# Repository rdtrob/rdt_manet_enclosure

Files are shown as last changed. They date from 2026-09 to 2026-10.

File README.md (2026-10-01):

# RDT MANET Radio Enclosure

A 3D-printable, weather-resistant and waterproof enclosure for a portable mesh radio node built around the Raspberry Pi Compute Module 4, Waveshare Mini Base Board (A), MediaTek MT7916 Wi-Fi 6E card and a Morse Micro MM8108 Wi-Fi HaLow board.

The enclosure was designed for the [very-srs/MANET](https://github.com/very-srs/MANET) project (on the Waveshare CM4 carrier board), but it should also fit hardware deployments of [OpenMANET](https://github.com/openmanet) (Raspberry Pi 4/5) with minimal to no required modifications.

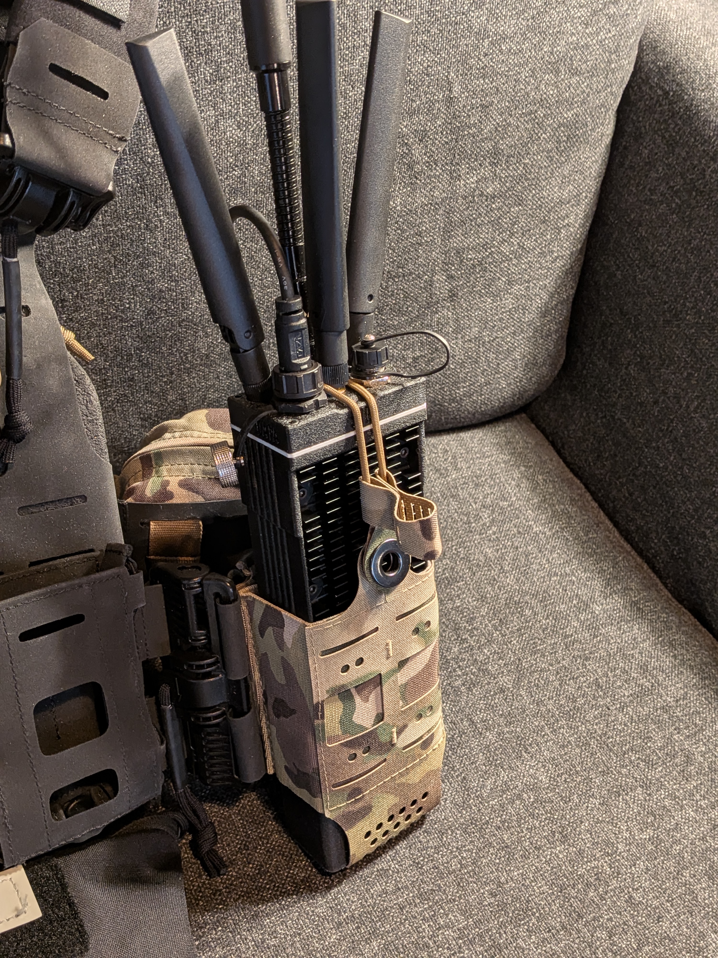
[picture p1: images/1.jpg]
Plate carrier presentation

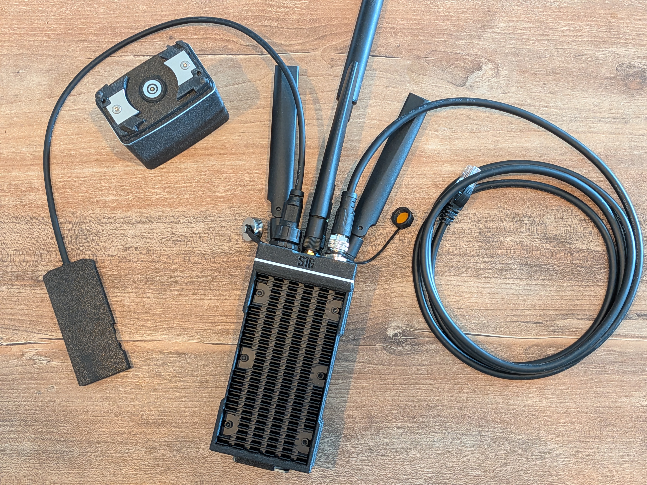
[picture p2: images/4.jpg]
Assembled enclosure with accessories, next to battery.


More pictures can be found in [images/](images/)

---

## Table of Contents

- [Overview](#overview)
- [Features](#features)
- [Compatible Hardware](#compatible-hardware)
- [Bill of Materials](#bill-of-materials)
- [Repository Structure](#repository-structure)
- [Printing](#printing)
- [Assembly](#assembly)
- [Power](#power)
- [Thermal Notes](#thermal-notes)
- [RF Notes](#rf-notes)
- [Software](#software)
- [Contributing](#contributing)
- [License](#license)
- [Disclaimer](#disclaimer)
- [Acknowledgements](#acknowledgements)

---

## Overview

This repository contains the printable parts (STL) for a self-contained MANET radio node. The enclosure houses:

- **Raspberry Pi CM4** on a **Waveshare Mini Base Board (A)** carrier,
- **MT7916 Wi-Fi 6E M.2 A/E-key card**, mounted in the carrier's M.2 M-key slot through an **M.2 M-key → A/E-key adapter (Note: Only two of the three antennas send, specifically 1 and 2, the ones on the short end of the MT7916 board. The 3rd is only receiving on 5GHz in 2T3R mode.)**,
- **Lunpid Morse Micro MM8108 Wi-Fi HaLow** board connected over USB-C,
- **Pololu D36V28F5** 5 V step-down regulator,

and exposes three SMA antenna ports for the MT7916, one SMA port for the HaLow radio, a waterproof USB-C port, an M12 connector to internal Ethernet port and a magnetic pogo-pin power input.

## Features

- Fully 3D-printable body, no custom PCBs required
- 3× SMA bulkhead mounts for 2.4 / 5 / 6 GHz MIMO antennas (Note: see reference to antenna positioning in the [Overview](#overview) section above, subsection MT7916)
- 1× SMA bulkhead mount for the sub-GHz HaLow antenna
- Waterproof panel-mount USB-C for access to the carrier board
- M12 connector for ruggedized wired Ethernet
- 3-pin magnetic pogo-pin power input, regulated on board to 5 V
- Heat-set-insert design using M2.5 and M3 hardware
- Cables

## Compatible Hardware

| Component | Model | Notes |
|---|---|---|
| Compute | Raspberry Pi Compute Module 4 — CM4004032 | 4 GB RAM, 32 GB eMMC, **no** onboard Wi-Fi/BT requried |
| Carrier | Waveshare Mini Base Board (A) (CM4-IO-BASE-A) | Gigabit Ethernet, 2× USB 2.0, M.2 M-key (PCIe), 5 V USB-C input |
| Wi-Fi 6E | AsiaRF AW7916-AED (MediaTek MT7916AN) | M.2 A/E-key, 2.4 GHz 2T2R + 5/6 GHz, 3× IPEX antenna connectors |
| M.2 adapter | M.2 M-key → M.2 A/E-key adapter | Lets the A/E-key Wi-Fi card sit in the carrier's M-key slot |
| HaLow | Morse Micro MM8108 board | 802.11ah, connected to the carrier via USB-C |
| Regulator | Pololu D36V28F5 | 5 V, 3.2 A step-down; wide input range |
| Heatsink - MT7916 | Wakefield 559-50AB-ND | Heatsink for MT7916 card

Other CM4 variants (different RAM/eMMC sizes) fit the same carrier. Variants **with** onboard wireless also fit, but their onboard antenna will be shielded by the enclosure and are also not used.

## Bill of Materials

The full parts list, with quantities and supplier links, is in **[BOM.md](BOM.md)**.

Summary of what you'll need beyond the printed parts:

- Core electronics: CM4, carrier board, MT7916 card, M.2 adapter, MM8108 HaLow board, Pololu regulator
- Antennas: 3× SMA (2.4/5/6 GHz) + 1× SMA adapter for HaLow board
- Connectors and cables: waterproof USB-C, M12 Ethernet, magnetic pogo-pin power, USB-A to USB-C adapter, internal USB-C cables
- Hardware: Heatsink, M2.5 and M3 screws, M3 nuts

## Repository Structure

```
.
├── stl/              # Printable parts
├── source/           # Editable CAD source files (STEP / native format) #To be potentially added in the future
├── images/           # Photos and renders
├── docs/             # Additional assembly or wiring notes
├── BOM.md            # Bill of materials
├── LICENSE           # GNU GPL v3.0
└── README.md
```

| File | Part | Qty |
|---|---|---|
| `stl/Unibody.stl` | Main body  to be printed in PA6-GF | 1 |
| `stl/TopConnectorPlate.stl` | Top I/O plate - PA6-GF | 1 |
| `stl/BackPanel.stl` | Back panel - PA6-GF | 1 |
| `stl/TPU_gasket_back.stl` | Back gasket to be printed in TPU | 1 |
| `stl/TPU_gasket_top` | Top gasket - TPU | 1 |
| `stl/Connector_MagneticPogoPIN_mount` | Pogo-pin connector mounting bracket - PA6-GF | 1 |
| `stl/Connector_MagneticPogoPIN_TPU_gasket` | Pogo-pin connector gasket - TPU | 1 |

## Printing

Recommended settings (adjust for your printer):

| Setting | Value |
|---|---|
| Material | PA6-GF or PETG-CF for enclosure and TPU for gaskets|
| Layer height | 0.08 mm |
| Walls / perimeters | 2 - 4 |
| Infill | 35 %  to 45 % |
| Supports | Default, tree |
| Nozzle | 0.4 mm |

Notes:
- Avoid PLA for field units: it softens in direct sunlight and in a warm vehicle.
- Print the body with the bottom side up ( battery connector facing upwards ) or front-facing open side up for the cleanest sealing surface.
- Print with supports. Yes, there's some filament loss in support material on the BackPanel and TopConnectorPlate designs but the prints come out clean, with minimal to no retouching required.
- Test-fit the SMA bulkheads and M12 connector before final assembly; hole tolerances vary between printers.
- For waterproof-sealing, treat all printed components with a polimer sealant like Diamant's Dichtol AM Hydro (Note: link provided in **[BOM.md](BOM.md)**)

## Assembly

<!-- TODO: expand with photos per step -->

1. **Prepare the compute stack.** Seat the CM4 on the Waveshare carrier. Install the M.2 M→A/E adapter in the carrier's M.2 slot and fit the MT7916 card to the adapter.
2. **Attach antenna pigtails.** Connect the three IPEX leads to the MT7916 card before mounting it; access is limited once installed.
3. **Mount bulkhead connectors.** Install the 3× SMA bulkheads, the HaLow SMA, the waterproof USB-C, the M12 connector and the magnetic pogo-pin connector in the enclosure walls.
4. **Mount the carrier.** Fix the carrier into the body with M2.5 screws.
5. **Mount the Pololu regulator** with M3 hardware and wire it: pogo-pin input → Pololu VIN/GND, Pololu 5 V output → USB-C cable → carrier board power input.
6. **Mount the HaLow board** and connect it to the carrier with the short USB-C to USB-C cable. Connect its antenna lead to the HaLow SMA bulkhead.
7. **Connect Ethernet:** carrier RJ45 → M12 internal cable.
8. **Close the enclosure** with M3 screws and nuts. Check that no cable is pinched at the lid seam.

## Power

```
[External source] ──► 3-pin magnetic pogo connector ──► Pololu D36V28F5 (5 V) ──► USB-C ──► Waveshare carrier
                                                                                              ├── CM4
                                                                                              ├── M.2 → MT7916 (3.3 V rail)
                                                                                              └── USB-C → MM8108 HaLow
```

- The D36V28F5 accepts a wide input range and outputs a regulated 5 V. **Check the input limits on the Pololu product page before connecting any source.**
- Double-check pogo-pin polarity before first power-up. There is no reverse-polarity protection in this design unless you add it. <!-- TODO: confirm -->
- The Waveshare carrier's 5 V input is specified for about 2.5 A. The MT7916 card is the biggest single load; see below.

## Thermal Notes

- The MT7916 card can draw several watts under load and needs its heatsink fitted.
- The CM4 benefits from a heatsink, especially in a sealed enclosure. 
- A sealed printed enclosure has limited heat dissipation. For sustained high-throughput use or hot climates, consider reducing Wi-Fi TX power or adding ventilation.

## RF Notes

- Use antennas rated for the bands you operate on (2.4 / 5 / 6 GHz for the MT7916; your regional sub-GHz band for HaLow).
- Never transmit without antennas connected, can damage components.
- Keep IPEX-to-SMA pigtails short and avoid sharp bends.
- **You are responsible for operating within your local regulatory limits** (channels, transmit power, EIRP, 6 GHz availability).

## Software

This repository contains **hardware only**. For firmware and mesh configuration see:

- [very-srs/MANET](https://github.com/very-srs/MANET). This enclosure is primarily designed for use with the very-srs project but can fit OpenMANET as well.
- [OpenMANET](https://github.com/openmanet)

## Contributing

Issues and pull requests are welcome.

- Describe what you changed and why (fit issue, new variant, print improvement).
- Include the **editable source file** along with any updated STL.
- Note the printer, material and settings you tested with.
- Photos of printed or assembled parts are very helpful.

## License

This project is licensed under the **GNU General Public License v3.0**. See [LICENSE](LICENSE).

You may use, modify and redistribute these files, including commercially, provided that any distributed derivative is released under the same license and includes its corresponding source files.

Third-party components listed in the BOM are the property of their respective manufacturers and are not covered by this license.

## Disclaimer

This design is provided **as is, without warranty of any kind**. You assume all risk associated with building, powering and operating this device, including electrical safety, battery handling, weatherproofing and radio-regulatory compliance.

## Acknowledgements

- [very-srs/MANET](https://github.com/very-srs/MANET) and [OpenMANET](https://github.com/openmanet) projects.
- Raspberry Pi, Waveshare, AsiaRF, Morse Micro and Pololu for the hardware.

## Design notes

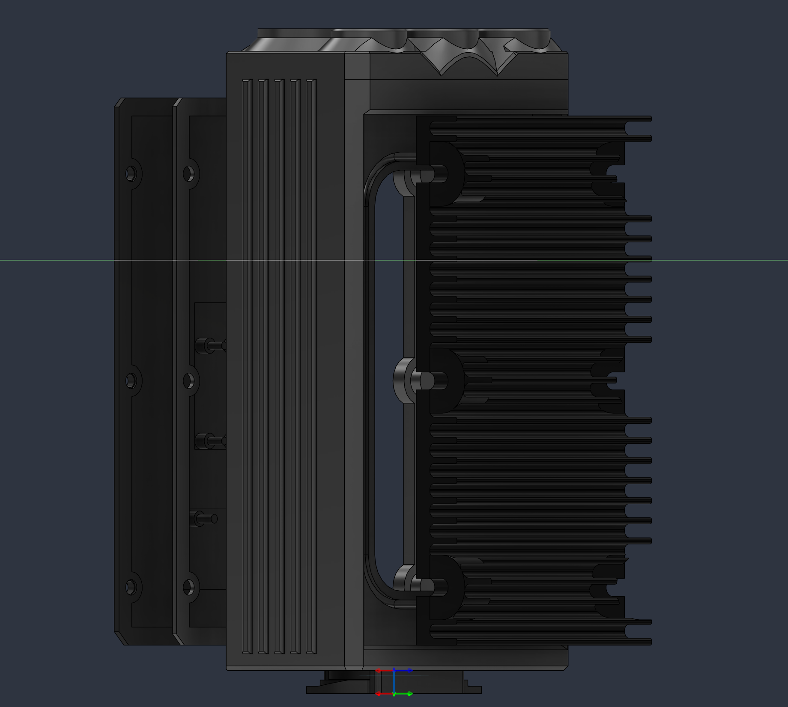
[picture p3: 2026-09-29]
images/render/render_4.png

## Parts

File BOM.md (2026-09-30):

# Bill of Materials

Parts required to build one radio node. Printed parts are listed in the [README](README.md#repository-structure).

Links are provided for reference only; equivalent parts from other suppliers should work unless noted.

## Electronics

| # | Name | Description | Amount | Link |
|---|---|---|---|---|
| 1 | Raspberry Pi Compute Module 4 | CM4004032: 4 GB RAM, 32 GB eMMC, no onboard Wi-Fi/BT | 1 | [PiShop](https://www.pishop.us/product/raspberry-pi-compute-module-4-4gb-32gb-cm4004032/) |
| 2 | CM4 carrier board | Waveshare Mini Base Board (A) (CM4-IO-BASE-A) | 1 | [Eckstein](https://eckstein-shop.de/WaveShareMiniBaseBoardADesignedforRaspberryPiComputeModule4) |
| 3 | MT7916 Wi-Fi 6E board | AsiaRF AW7916-AED, M.2 A/E-key, MediaTek MT7916AN | 1 | [AsiaRF](https://asiarf.com/product/wi-fi-6e-m-2-ae-key-module-mt7916-aw7916-aed/) |
| 4 | M.2 A/E-key adapter | M.2 M-key to M.2 A/E-key adapter for the Wi-Fi board | 1 | [AliExpress](https://www.aliexpress.com/item/4000175123887.html) |
| 5 | MM8108 HaLow board | Morse Micro MM8108 Wi-Fi HaLow (802.11ah) board | 1 | [Shopify Lunpid](https://lunpid.com/products/usb-mm8108-halow) |
| 6 | Pololu buck converter | Pololu D36V28F5, 5 V 3.2 A step-down regulator | 1 | [Pololu](https://www.pololu.com/product/3782) |

## Antennas and RF

| # | Name | Description | Amount | Link |
|---|---|---|---|---|
| 7 | SMA antenna | 2.4 / 5 / 6 GHz antenna for the MT7916 board | 3 | [Farnell](https://www.newark.com/siretta/delta47-smam-36/rf-antenna-600mhz-5-6ghz/dp/97AK2184) |
| 8 | SMA antenna (HaLow) | 868 MHz SMA antenna for the Lunpid MM8108 HaLow board | 1 | [Hexaspot 868MHz gooseneck antenna](https://hexaspot.com/products/hexaspot-tactical-gooseneck-antenna-868mhz?variant=57776200810827) |
| 9 | SMA cable, 2.4/5GHz | IPEX MHF 1 - SMA female cable assembly for MT7916 board | 3 | [TME](https://www.tme.eu/en/details/ipex-sma-150/coaxial-assemblies/onteck)
| 10 | SMA cable, sub 1GHz | Ccable for SMA male to SMA female adapter for the MM8108 HaLow board antenna | 1 | [AliExpress](https://www.aliexpress.com/item/1005003433705318.html) |

## Connectors and Cables

| # | Name | Description | Amount | Link |
|---|---|---|---|---|
| 11 | Waterproof USB-C connector | Panel-mount waterproof USB-C, wired to the carrier board | 1 | [AliExpress](https://www.aliexpress.com/item/1005006218980573.html) |
| 12 | USB-C cable & connector (Pololu → carrier) | Cable with USB-C plug carrying 5 V from the Pololu board to the carrier board | 1 | [AliExpress](https://www.aliexpress.com/item/1005011867528852.html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) |
| 13 | Pololu → pogo-pin cable | Cable from the Pololu input to a 3-pin magnetic pogo-pin connector | 1 | [AliExpress](N/A) |
| 14 | Magnetic Pogo 3 Pin connector | Panel-mount circular 12mm connector, wired to the #11 cable. Connects to the off-set connector on the battery enclosure. | 1 | [AliExpress](https://www.aliexpress.com/item/1005008792560196.html#nav-specification)
| 15 | USB-C snap connector UC1 | Snap USB-C connector, Lunpid MM8108 HaLow board | 1 | [AliExpress](https://www.aliexpress.com/item/1005008383845058.html) |
| 15 | Ribbon cable for USB-C snap connector | Short cable, carrier board to Lunpid MM8108 HaLow USB-C snap connector | 1 | [AliExpress](https://www.aliexpress.com/item/1005008383845058.html) |
| 16 | M12 connector | Panel-mount M12 connector for Ethernet. Pick Male Back M12-P-GCFM-16-NZG 8Pin variant. | 1 | [AliExpress](https://www.aliexpress.com/item/1005012293627764.html) |
| 17 | Flat Ethernet connector | Internal connector, M12 connector to carrier RJ45 port | 1 | [AliExpress](https://www.aliexpress.com/item/1005005257546532.html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) |
| 18 | USB adapter | USB-A to USB-C(female) adapter for external USB-C connector to be plugged into the carrier board | 1 | [AliExpress](https://www.aliexpress.com/item/1005009180629876.html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) |

## Hardware

| # | Name | Description | Amount | Link |
|---|---|---|---|---|
| 19 | Heatsink for MT7916 | Wakefield 559-50AB-ND heatsink | 1 | [Wakefield 559-50AB](https://www.digikey.com/en/products/detail/wakefield-thermal-solutions/559-50ab/5068188)* |
| 20 | M2.5 screws | Hex M2.5x7mm | 4 | N/A |
| 21 | M3 screws, back plate | Hex M3x6mm, mounting the back plate | 6 | N/A |
| 22 | M3 screws, front plate | Hex M3x8mm, mounting the front Heatsink | 6 | N/A |
| 23 | M3 screws, top I/O plate | Hex M3x12mm, mounting the top I/O plate | 4 | N/A
| 24 | M3 nuts | Standard Hex, mounting the grounding bar, Pogo PIN TPU gasket and mounting plate | 2 | N/A |
| 25 | M2.5 heat-set inserts | M2.5\*4\*3.5mm Heat-set inserts, mounting the CM4 carrier board | 4 | N/A |
| 26 | M3 heat-set inserts | M3\*4\*4mm Heat-set inserts for mounting the front, back and top plates to the enclosure | 16 | N/A |

## Misc
| # | Name | Description | Amount | Link |
|---|---|---|---|---|
| 27 | Diamant Dichtol AM Hydro | Polimer sealant for additive manufacturing | 1 | [Diamant Dichtol AM Hydro](https://diamant-polymer.de/en/industry/3d-printing-additive-manufacturing/impregnating-and-sealing/make-3d-print-waterproof) |
| 28 | Grounding bar and wings assembly | Mesh node side of the twist-lock assembly | 1(each) | ** - Check [Notes](#notes)
| 29 | Rubber seal | 2mm cylindrical rubber seal, pressed in under-heatsink groove to prevent water and dust from seeping in | 1 | [AliExpress](https://www.aliexpress.com/item/1005011949296931.html) |

## Notes

- Quantities are for **one** unit.
- Confirm antenna connector gender (SMA vs RP-SMA) matches your bulkheads before ordering.
- If purchasing a different buck board model, check the input voltage range against your power source.
- \* If the thermal transfer isn't required and a completely FDM enclosure is wanted instead, the 3D model for the Wakefield Heatsink can be found here [Mouser](https://www.mouser.com/en/ProductDetail/Wakefield-Thermal/559-50AB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)
- \*\* SupplyNet provides both the wings and grounding bar for sale. If sourcing isn't available, models for both components can be found [here](https://www.thesupplynet.com/Attachment/DownloadFile?downloadId=779)( 1x GND bar ) and [here](https://www.thesupplynet.com/Attachment/DownloadFile?downloadId=83)( left and right wings, one of each ) for FDM printing or CNC machining.

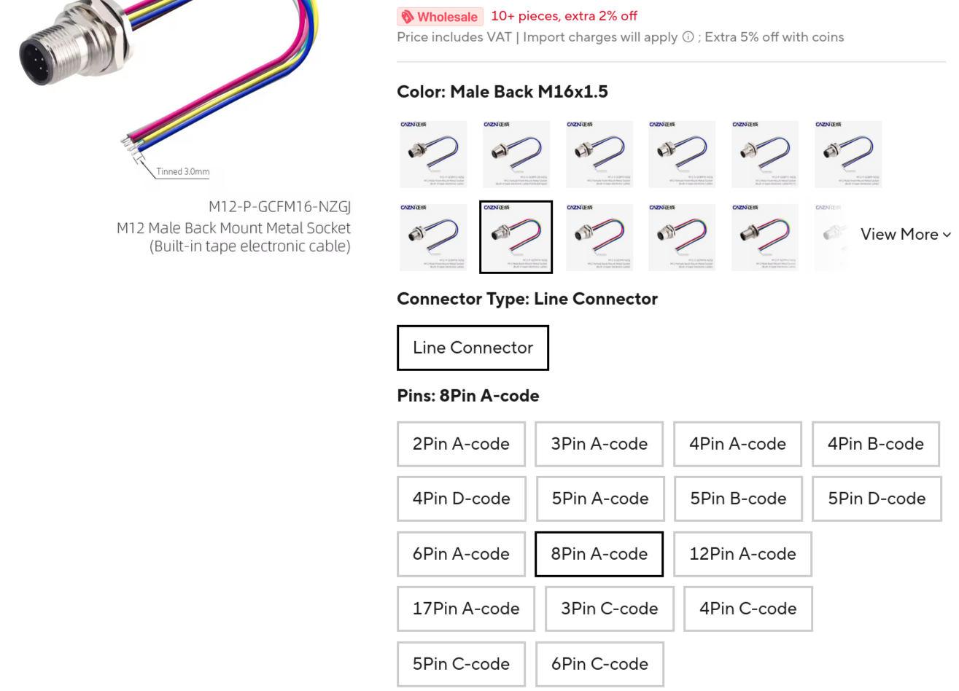
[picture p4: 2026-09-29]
images/components/m12_8PIN_connector.png

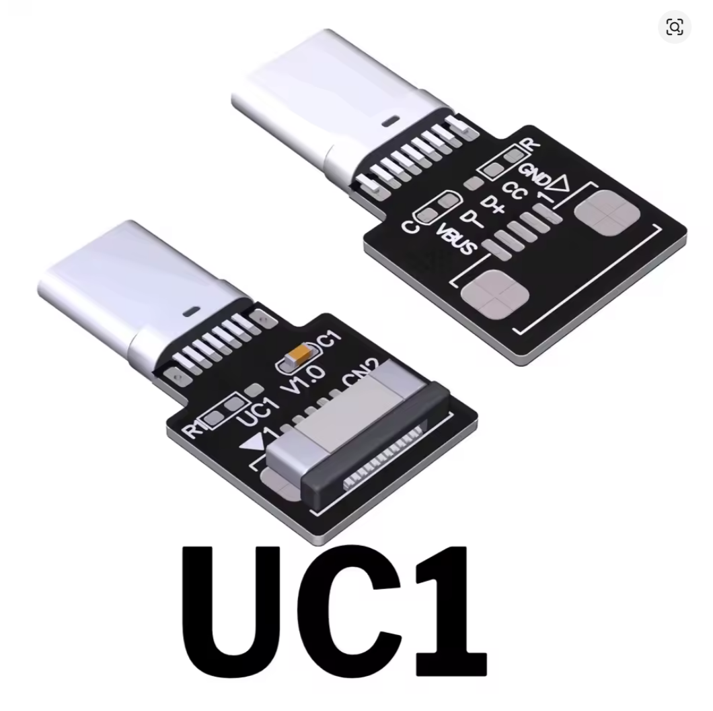
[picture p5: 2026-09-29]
images/components/USB-C_ribbon_connector.png

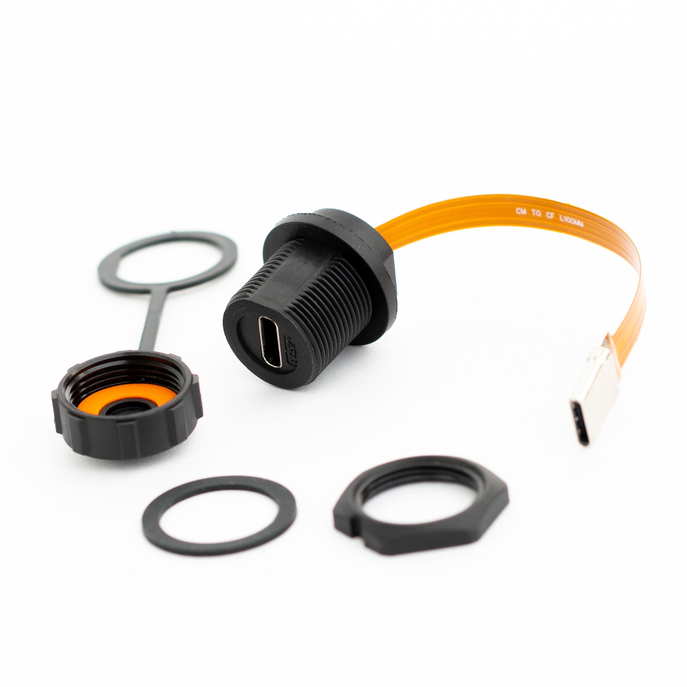
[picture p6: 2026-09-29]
images/components/CAZN_USB-C_connector.jpg

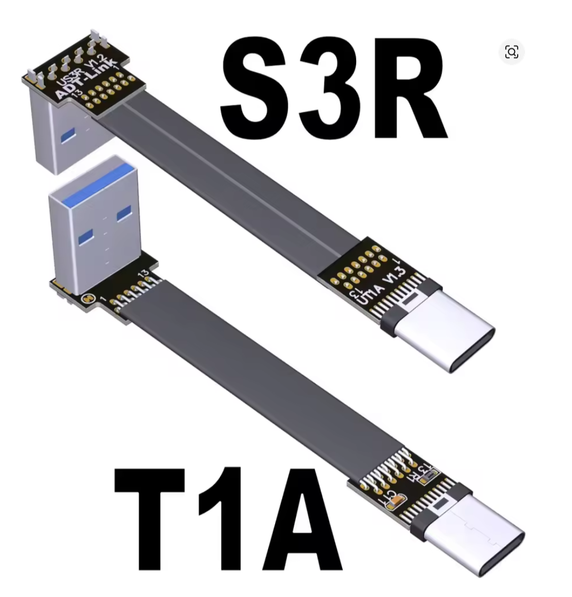
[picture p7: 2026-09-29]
images/components/USB-A_to_USB-C_angled_connector.png

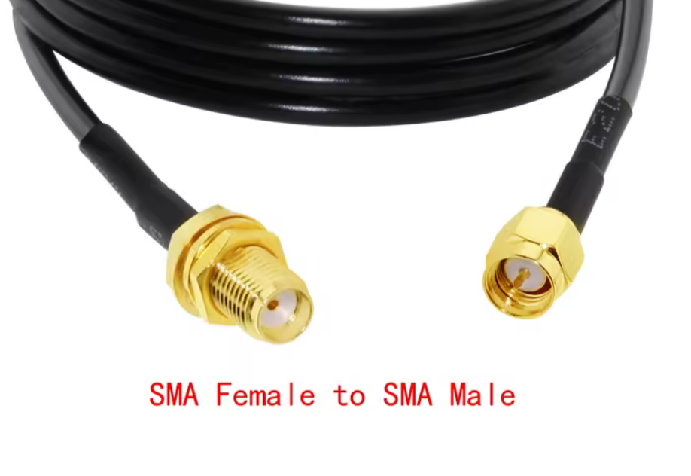
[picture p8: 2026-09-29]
images/components/SMA-male_to_SMA-female_connector.png

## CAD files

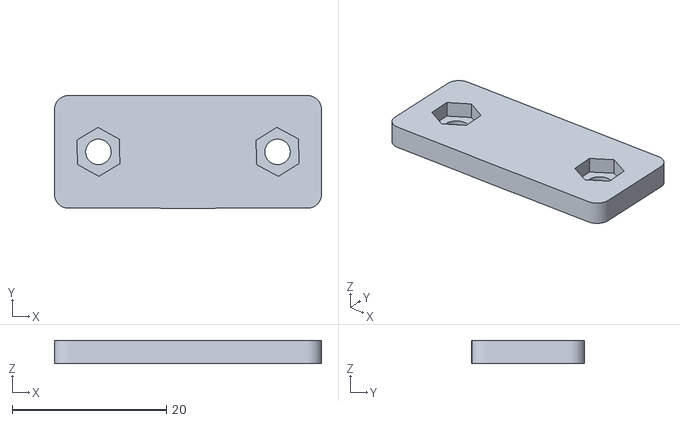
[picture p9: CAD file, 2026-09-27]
stl/Connector_MagneticPogoPIN_mount.stl
34.6 x 14.6 x 3.00

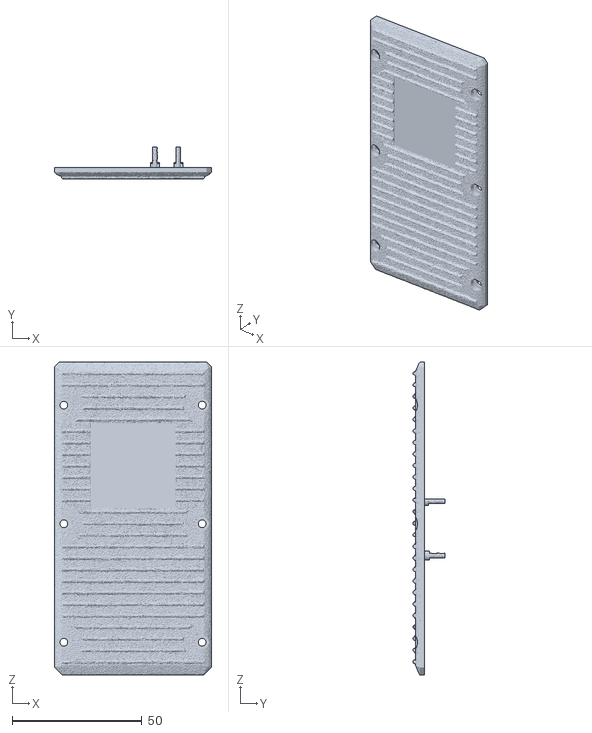
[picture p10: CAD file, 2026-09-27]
stl/BackPanel.stl
60.6 x 12.5 x 120.7

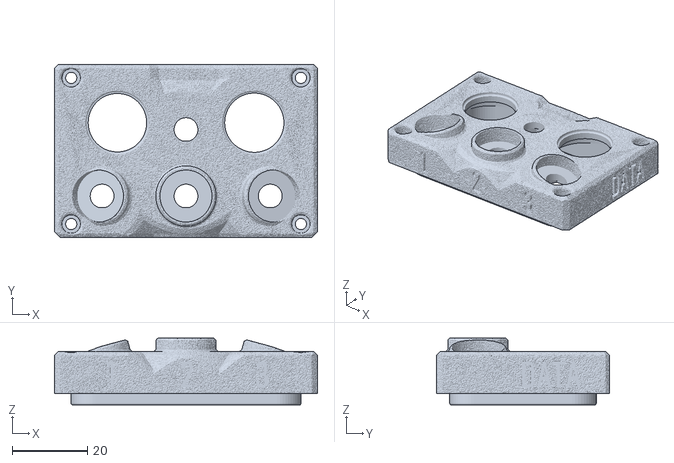
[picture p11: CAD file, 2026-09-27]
stl/TopConnectorPlate.stl
70.1 x 46.1 x 17.8

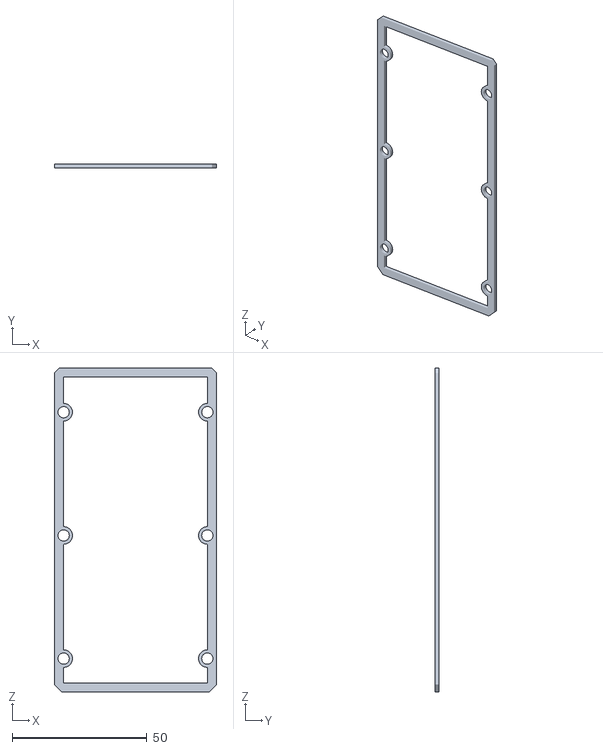
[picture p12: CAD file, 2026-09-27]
stl/TPU_gasket_back.stl
60.2 x 1.50 x 120.3

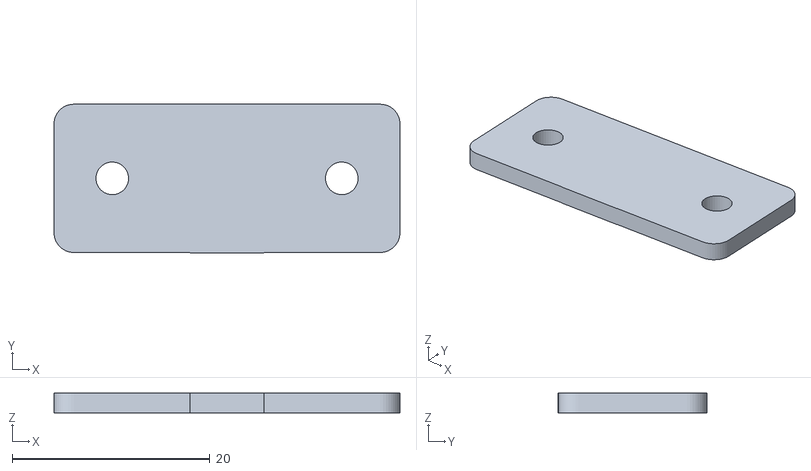
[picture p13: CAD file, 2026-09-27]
stl/Connector_MagneticPogoPIN_TPU_gasket.stl
35.0 x 15.0 x 2.00

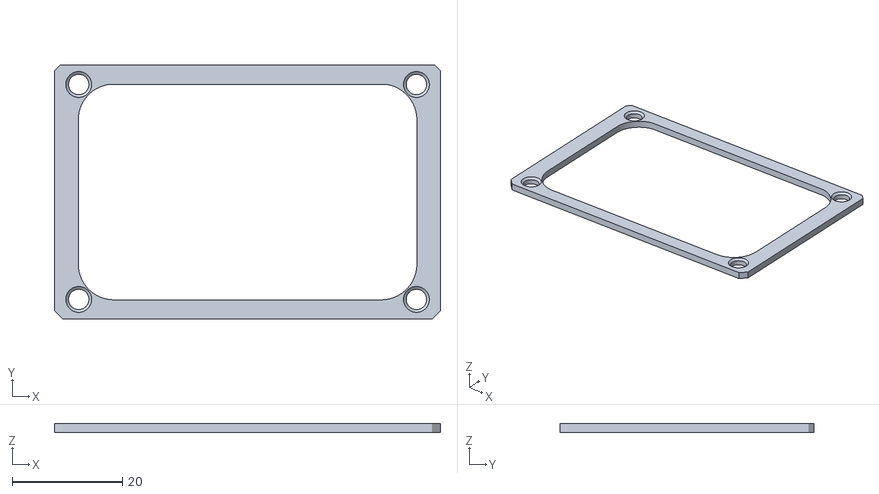
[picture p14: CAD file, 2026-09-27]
stl/TPU_gasket_top.stl
70.0 x 46.0 x 1.60

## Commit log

2026-09-27 Pushed .stl files, added BOM.md and updated README.md
    [BackPanel.stl, Connector_MagneticPogoPIN_TPU_gasket.stl, Connector_MagneticPogoPIN_mount.stl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]
2026-09-28 Updated BOM and README.
2026-09-29 Updated BOM
2026-09-29 Fixed table entry for polymer sealant in BOM
2026-09-29 Added reference and links to grounding bar and wings for the twist-lock mechanism assembly for the mesh node.
2026-09-30 Clarified purpose of grounding bar and wings assembly
2026-09-30 Added entry on supports when printing the enclosure
2026-09-30 Added reference and link to 3d model for the Front Heatsink to be printed in PA6-GF or PETG-CF instead.
2026-09-30 Added reference to USB adapter (USB-A_to_USB-C) for external USB-C connector to carrier board connectivity
2026-10-01 Updated reference pictures of assembled enclosure
2026-10-12 Added note and link on voltage regulator feature-set.
2026-10-14 Added editable assembly file.
